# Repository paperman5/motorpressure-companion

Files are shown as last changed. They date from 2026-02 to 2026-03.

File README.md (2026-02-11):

WIP project to create a companion add-on board for [Altus Metrum](https://altusmetrum.org/) flight computers. This companion board is intended to transmit realtime pressure data to the flight computer using a high-pressure pressure sensor for motor characterization similar to the [EasyMotor](https://altusmetrum.org/EasyMotor/), using a low-cost Cortex M0 based microcontroller board ([Adafruit Feather M0 Adalogger](https://www.adafruit.com/product/2796)).

### External Libraries
This project uses the [SercomSPISlave](https://github.com/lenvm/SercomSPISlave) library, since there is no built-in support for using this board in SPI slave mode within Adafruit's libraries. Currently an SPI slave is created using the general-purpose configurable serial port SERCOM4 on the M0.

### Companion Port Pinout
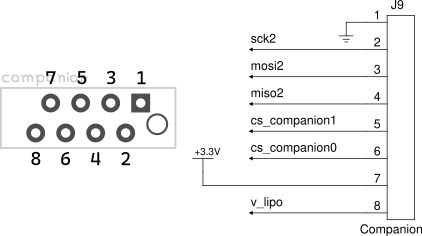
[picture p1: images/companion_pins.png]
Companion Port Pins


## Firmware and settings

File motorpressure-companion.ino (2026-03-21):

// #define REGISTER_DEBUG
// #define ADC_TEST_VALUES // Replaces ADC values with a monotonically increasing value for testing
// #define TRANSMIT_TEST_VALUES // Replaces transmit buffer with testing values
// #define TEST_FLIGHT_TRIGGER
// #define USB_CONNECTED

#include <SPI.h>
#include <FreeStack.h>
#include <SdFat.h>
#include <SdFatConfig.h>
#include <SdFatDebugConfig.h>
#include <sdios.h>
#include <SercomSPISlave.h>
#ifdef REGISTER_DEBUG
  #include <ZeroRegs.h>
#endif

// WIRING (Adafruit Feather M0 Adalogger)
// Flight Computer MOSI <-> Feather PA16 (Labelled D11)
// Flight Computer SCK  <-> Feather PA17 (Labelled D13)
// Flight Computer CS   <-> Feather PA18 (Labelled D10)
// Flight Computer MISO <-> Feather PA19 (Labelled D12)
// Pressure sensor output <-> Feather PB08 (Labelled A1) (3.3V MAX!)

#define CHANNELS 12
#define PACKED_CHANNELS CHANNELS * 4 / 3
#define BOARD_ID 0x7
#define UPDATE_RATE 1 // Companion port update rate, 100Hz ticks
#define ADC_RATE 10 // 1kHz increments, min 1, max 12 (1-12kHz)
#define TRANSMIT_RATE_IDLE 1000   // Radio transmission rate while on the pad/after motor burn (1Hz)
#define TRANSMIT_RATE_FLIGHT 100  // Radio transmission rate while motor is burning (10Hz)
#define FIFO_SIZE 1024
#define SD_MAX_CLOCK 24 // Mhz
#define SD_MIN_CLOCK 8  // Mhz
#define SD_FAT_TYPE 3 // 1 for FAT16/FAT32, 2 for exFAT, 3 for FAT16/FAT32 and exFAT.
#define PIN_SD_CS 4
#define PIN_SD_LED 8
#define ERR_PATTERN_LENGTH 150 // millis between morse code beeps
#define DATA_FILE_PREALLOCATE ADC_RATE * 1000 * 4 * 30  // 4 bytes @ ADC_RATE for 30s
#define SD_WRITE_CHUNK_SIZE 512
#define POST_BURNOUT_DELAY 1 // Additional time to log data after motor has burned out
#define DISCONNECT_RECORD_TIME 15 // Total time to record in case flight computer is disconnected after boost

#if SD_FAT_TYPE == 0
typedef SdFat sd_t;
typedef File file_t;
#elif SD_FAT_TYPE == 1
typedef SdFat32 sd_t;
typedef File32 file_t;
#elif SD_FAT_TYPE == 2
typedef SdExFat sd_t;
typedef ExFile file_t;
#elif SD_FAT_TYPE == 3
typedef SdFs sd_t;
typedef FsFile file_t;
#else  // SD_FAT_TYPE
#error Invalid SD_FAT_TYPE
#endif  // SD_FAT_TYPE

enum Command {
  SETUP = 1,
  FETCH = 2,
  NOTIFY = 3
};
enum FlightState { // From firmware kernel source `ao_flight.h`
  STARTUP = 0,
  IDLE = 1,
  PAD = 2,
  // PAD->BOOST: Baro >20m vert OR accel >2g && vel > 5m/s
  BOOST = 3,
  // BOOST->FAST: accel < -1/4g OR boost time > 15s
  FAST = 4,
  COAST = 5,
  DROGUE = 6,
  MAIN = 7,
  LANDED = 8,
  INVALID = 9,
  TEST = 10
};
enum Error {
  SD_NOT_FOUND = 0,
  SD_FILE_CREATE_ERR = 1,
  SD_FILE_CLOSE_ERR = 2
};
enum ProgramState {
  DISCONNECTED = 0,
  MONITORING = 1,
  RECORDING = 2,
  DONE = 3,
  ERROR = -1
};

// The companion docs are incorrect, the message header is 16 bytes, not 8 bytes.
// There is some extra data after the flight number (from firmware source)
typedef struct {
  volatile uint8_t command;
  volatile uint8_t flight_state;
  volatile uint16_t tick;
  uint16_t         serial;
  uint16_t         flight; // End of companion docs
  volatile int16_t accel;  // From firmware source
	volatile int16_t speed;
	volatile int16_t height;
	uint16_t	       motor_number;
} AltOSMessageHeader;

typedef struct {
  uint16_t board_id;
  uint16_t board_id_inverse;
  uint8_t update_period;
  uint8_t channels;
} AltOSSetupReply;

typedef struct {
  volatile uint16_t data[CHANNELS];
} AltOSFetchReply;

typedef struct {
  uint16_t tick;
  uint16_t value;
} data_t;

Sercom1SPISlave SPISlave;
AltOSMessageHeader message;
AltOSSetupReply setupReply;
AltOSFetchReply fetchReply;
volatile ProgramState state = DISCONNECTED;
ProgramState prevState = DISCONNECTED;
FlightState prevFlightState = INVALID;
sd_t sd;
file_t dataFile;
bool fileCreated = false;
uint8_t rxIndex = 0;
uint8_t txIndex = 0;
uint8_t transmitIndex = 0;
uint16_t dataIndex = 0;
volatile data_t currentData;
// NOTE: `volatile` before pointer type means value at the pointer is volatile,
// `volatile` after pointer type means pointer itself is volatile
volatile data_t dataFifo0[FIFO_SIZE];
volatile data_t dataFifo1[FIFO_SIZE];
// Circular buffer to keep a history of decimated ADC values.
volatile uint16_t transmitBuffer[PACKED_CHANNELS * 2];
// Packed 12bit buffer storing the most recent decimated ADC values for transmission.
// Copied to `fetchReply.data` as soon as a FETCH request is received.
volatile uint8_t tempDataTransmit[CHANNELS * 2];
volatile data_t* volatile currentDataBuffer = dataFifo0;
volatile data_t* volatile dataBufferToWrite = dataFifo1;
volatile bool doDataWrite = false;
volatile bool sdCardIsWriting = false;
volatile bool sdCardOverrun = false;
volatile bool sdCardConnected = false;
volatile bool companionConnected = false;
volatile bool sdInterruptToggleMode = false;
volatile bool companionInterruptToggleMode = false;
volatile bool newMessage = false;
volatile bool isFlightDecimation = false;
volatile uint32_t finalizeDelayTimer = 0;
volatile uint32_t finalizeDelay = 0;
volatile uint32_t adcTicks = 0;
#ifdef ADC_TEST_VALUES
volatile uint16_t adcIndex = 0;
#endif

uint16_t writeCount = 0;
uint32_t loopCount = 0;
uint32_t loopCount2 = 0;


/****** MAIN PROGRAM ******/

void setup() {
  pinMode(PIN_SD_LED, OUTPUT);
  digitalWrite(PIN_SD_LED, LOW);
  Serial.begin(115200);
#ifdef USB_CONNECTED
  while (!Serial);
#endif
  Serial.println(F("Serial started"));

  setupReply.board_id = (uint16_t)BOARD_ID;
  setupReply.board_id_inverse = ~setupReply.board_id;
  setupReply.update_period = (uint8_t)UPDATE_RATE;
  setupReply.channels = (uint8_t)CHANNELS;
  message.command = 0;
  message.flight_state = (uint8_t)INVALID;
  for (int i = 0; i < CHANNELS; i++) {
    fetchReply.data[i] = i;
  }
  memset_volatile(dataFifo0, 0, sizeof(dataFifo0));
  memset_volatile(dataFifo1, 0, sizeof(dataFifo1));
  Serial.print(F("Setup reply initialized: "));
  Serial.printf("%d %d %d %d\n", 
                setupReply.board_id, setupReply.board_id_inverse, 
                setupReply.update_period, setupReply.channels);
  
  init_clocks();
  Serial.println(F("System clocks initialized"));
  SPISlave.SercomInit(SPISlave.MOSI_Pins::PA16, SPISlave.SCK_Pins::PA17, SPISlave.SS_Pins::PA18, SPISlave.MISO_Pins::PA19);
  Serial.println(F("SERCOM1 SPI slave initialized"));
  init_adc();
  Serial.println(F("ADC Initialized"));
  init_adc_timer();
  init_decimation_timer();
  // set_idle_decimation();
  set_flight_decimation();
  Serial.println(F("Timers Initialized"));
  init_eic();
  Serial.println(F("EIC Initialized"));
  // if (!sdCardConnected) {
  //   Serial.println(F("Waiting for SD card to be inserted"));
  //   while(!sdCardConnected) {
  //     delay(100);
  //   }
  // }
  sd_card_init();
  Serial.println(F("SD Card Initialized"));
  // TODO: Setup brownout detector?
  Serial.print(F("Free Stack: "));
  Serial.printf("%d bytes\n", FreeStack());
#ifdef REGISTER_DEBUG
  ZeroRegOptions opts = { Serial, false };
  printZeroRegs(opts);
#endif
  char pattern[3];
  memset(pattern, 1, sizeof(pattern));
  err_blink_pattern(pattern, sizeof(pattern));
}

void loop() {
  // if (newMessage) {
  //   // Serial.println(F("Received Message"));
  //   // print_raw(&message, sizeof(message));
  //   Serial.printf("%d %d %d %d %d %d %d %d %d\n", message.command, message.flight_state, message.tick, 
  //                                                   message.serial, message.flight, message.accel, message.speed, 
  //                                                   message.height, message.motor_number);
  //   newMessage = false;
  // }
  FlightState newFlightState = static_cast<FlightState>(message.flight_state);
  if (prevFlightState != newFlightState) {
    handle_flight_state_change(prevFlightState, newFlightState);
  }
  ProgramState newState = state;
  if (prevState != newState) {
    handle_state_change(prevState, newState);
  }

#ifdef TEST_FLIGHT_TRIGGER
  //TESTING - Trigger flight after 4M loops in MONITORING
  if (newState == MONITORING) {
    loopCount2++;
    if (loopCount2 >= 4000000 && loopCount2 < 4500000) {
      state = RECORDING;
      finalizeDelayTimer = 0;
      finalizeDelay = DISCONNECT_RECORD_TIME;
    }
  }
#endif

  if (newState == RECORDING && doDataWrite) {
    // Serial.println(F("WRITE"));
    doDataWrite = false;
    sdCardIsWriting = true;
    sd_write_buffer_to_file(&dataFile, dataBufferToWrite, sizeof(dataFifo0));
    sdCardIsWriting = false;
    // writeCount++;
    // if (writeCount >= 75) {
    //   state = DONE;
    // }
  }
  else if (newState == RECORDING && finalizeDelayTimer >= (uint32_t)(finalizeDelay * ADC_RATE * 1000) && fileCreated) {
    // Serial.println("1");
    state = DONE;
  }
  if (sdCardOverrun) {
    sdCardOverrun = false;
    Serial.println(F("OVERRUN"));
  }
  if (newState == MONITORING && newFlightState == PAD && fileCreated) {
    digitalWrite(PIN_SD_LED, HIGH);
  }
  prevState = newState;
  prevFlightState = newFlightState;
  loopCount++;
}

void handle_state_change(ProgramState oldState, ProgramState newState) {
  Serial.printf("PROGRAM STATE: %d -> %d\n", oldState, newState);
  if (newState == MONITORING && !fileCreated) {
    Serial.println(F("Creating flight file"));
    if (!create_flight_file((uint8_t)message.flight)) {
      crash_with_error(SD_FILE_CREATE_ERR);
    }
    fileCreated = true;
    Serial.println(F("Flight file created on SD card"));
  }
  else if (newState == RECORDING) {
    set_flight_decimation();
    // set_idle_decimation();
  }
  else if (newState == DONE) {
    if (!finalize_file(&dataFile)) {
      crash_with_error(SD_FILE_CLOSE_ERR);
    }
    Serial.println(F("File Finalized, shutting down SD card"));
    sd.end();
    digitalWrite(PIN_SD_LED, HIGH);
    fileCreated = false;
    set_flight_decimation();
    // set_idle_decimation();
  }
}

void handle_flight_state_change(FlightState oldState, FlightState newState) {
  Serial.printf("FLIGHT STATE: %d -> %d\n", oldState, newState);
  if (newState == STARTUP) {
    if (fileCreated) {
      if (!finalize_file(&dataFile)) {
        crash_with_error(SD_FILE_CLOSE_ERR);
      }
      fileCreated = false;
    }
    state = MONITORING;
    set_flight_decimation();
    // set_idle_decimation();
  }
  else if (newState == BOOST) {
    state = RECORDING;
    finalizeDelayTimer = 0;
    finalizeDelay = DISCONNECT_RECORD_TIME;
    set_flight_decimation();
    // set_idle_decimation();
  }
  else if (oldState == BOOST && newState > BOOST) {
    // Serial.println("2");
    state = RECORDING;
    finalizeDelayTimer = 0;
    finalizeDelay = POST_BURNOUT_DELAY;
    set_flight_decimation();
    // set_idle_decimation();
  }
}

/****** PERIPHERAL REGISTER INITIALIZATION ******/

void init_clocks() {
  // Generic clock 0, is used for companion SPI connection (SERCOM1)
  // GCLK0 is also the main system clock so we don't change it or it will crash
  // GCLK1 is set up as the reference clock for the DFLL48 oscillator, don't change it

  // Load the factory clock calibration data
  uint32_t coarse = (*((uint32_t *) FUSES_DFLL48M_COARSE_CAL_ADDR) & FUSES_DFLL48M_COARSE_CAL_Msk) >> FUSES_DFLL48M_COARSE_CAL_Pos;
  uint32_t fine = (*((uint32_t *) FUSES_DFLL48M_FINE_CAL_ADDR) & FUSES_DFLL48M_FINE_CAL_Msk) >> FUSES_DFLL48M_FINE_CAL_Pos;
  SYSCTRL->DFLLVAL.reg = SYSCTRL_DFLLVAL_COARSE(coarse) | SYSCTRL_DFLLVAL_FINE(fine);

  // Generic clock 2, used for ADC clock
  // Setup with 48Mhz oscillator, divided by 3 for 16Mhz
  GCLK->GENDIV.reg = GCLK_GENDIV_ID(2) | GCLK_GENDIV_DIV(3);
  while (GCLK->STATUS.reg & GCLK_STATUS_SYNCBUSY);
  GCLK->GENCTRL.reg = GCLK_GENCTRL_GENEN | GCLK_GENCTRL_SRC_DFLL48M | GCLK_GENCTRL_ID(2);
  while (GCLK->STATUS.reg & GCLK_STATUS_SYNCBUSY);

  // Generic clock 3, used for Timer clock (TC5)
  // Setup with 48Mhz oscillator, divided by 4 for 12Mhz
  GCLK->GENDIV.reg = GCLK_GENDIV_ID(3) | GCLK_GENDIV_DIV(4);
  while (GCLK->STATUS.reg & GCLK_STATUS_SYNCBUSY);
  GCLK->GENCTRL.reg = GCLK_GENCTRL_GENEN | GCLK_GENCTRL_SRC_DFLL48M | GCLK_GENCTRL_ID(3);
  while (GCLK->STATUS.reg & GCLK_STATUS_SYNCBUSY);

  // Generic clock 4, used for External Interrupt Controller detection
  // Setup with 48Mhz oscillator, divided by 2^23 for 5Hz
  GCLK->GENDIV.reg = GCLK_GENDIV_ID(4) | GCLK_GENDIV_DIV(22);
  while (GCLK->STATUS.reg & GCLK_STATUS_SYNCBUSY);
  GCLK->GENCTRL.reg = GCLK_GENCTRL_GENEN | GCLK_GENCTRL_SRC_DFLL48M | GCLK_GENCTRL_ID(4) | GCLK_GENCTRL_DIVSEL;
  while (GCLK->STATUS.reg & GCLK_STATUS_SYNCBUSY);
}

void init_adc() {
  // // Configure I/O port - PA02 is PINCFG[2], PMUX[1].PMUXE
  // PORT->Group[PORTA].DIRCLR.reg = PORT_PA02;
  // PORT->Group[PORTA].PINCFG[2].bit.INEN = 0x1;
  // PORT->Group[PORTA].PINCFG[2].bit.PMUXEN = 0x1; // Enable pin PA02
  // PORT->Group[PORTA].PMUX[1].bit.PMUXE = 0x1; // Select peripheral function B (ADC input)

  // Configure I/O port - PB08 is GroupB, PINCFG[8], PMUX[4].PMUXE
  PORT->Group[PORTB].DIRCLR.reg |= PORT_PB08;
  PORT->Group[PORTB].PINCFG[8].bit.INEN = 0x1;
  PORT->Group[PORTB].PINCFG[8].bit.PMUXEN = 0x1; // Enable pin PB08
  PORT->Group[PORTB].PMUX[4].bit.PMUXE = 0x1; // Select peripheral function B (ADC input)

  // Reset ADC
  ADC->CTRLA.bit.ENABLE = 0x0;
  while (ADC->STATUS.bit.SYNCBUSY);
  ADC->CTRLA.bit.SWRST = 0x1;
  while (ADC->CTRLA.bit.SWRST || ADC->STATUS.bit.SYNCBUSY);

  // Configure ADC
  GCLK->CLKCTRL.reg = GCLK_CLKCTRL_ID(GCM_ADC) |  // Enable ADC clock
                      GCLK_CLKCTRL_GEN_GCLK2 |    // Use 16MHz GCLK2
                      GCLK_CLKCTRL_CLKEN;
  NVIC_EnableIRQ(ADC_IRQn); // Enable interrupt handler
  NVIC_SetPriority(ADC_IRQn, 1); // 2nd-highest priority
  while (GCLK->STATUS.reg & GCLK_STATUS_SYNCBUSY); // Wait for synchronisation

  // Load the factory calibration data
  // Code from https://blog.thea.codes/reading-analog-values-with-the-samd-adc/
  uint32_t bias = (*((uint32_t *) ADC_FUSES_BIASCAL_ADDR) & ADC_FUSES_BIASCAL_Msk) >> ADC_FUSES_BIASCAL_Pos;
  uint32_t linearity = (*((uint32_t *) ADC_FUSES_LINEARITY_0_ADDR) & ADC_FUSES_LINEARITY_0_Msk) >> ADC_FUSES_LINEARITY_0_Pos;
  linearity |= ((*((uint32_t *) ADC_FUSES_LINEARITY_1_ADDR) & ADC_FUSES_LINEARITY_1_Msk) >> ADC_FUSES_LINEARITY_1_Pos) << 5;
  while (ADC->STATUS.bit.SYNCBUSY);

  ADC->CALIB.reg = ADC_CALIB_BIAS_CAL(bias) | ADC_CALIB_LINEARITY_CAL(linearity);
  ADC->INPUTCTRL.bit.GAIN   = 0xF; // DIV2 gain due to voltage reference being 1/2 VCC
  ADC->INPUTCTRL.bit.MUXNEG = 0x18; // Internal ground as negative input
  // ADC->INPUTCTRL.bit.MUXPOS = 0x00; // PA02 (AIN0) as positive input
  ADC->INPUTCTRL.bit.MUXPOS = 0x02; // PB08 (AIN2) as positive input
  ADC->INTENSET.bit.RESRDY  = 0x1; // Enable result ready interrupt
  ADC->REFCTRL.bit.REFCOMP  = 0x1; // Enable voltage reference compensation
  ADC->REFCTRL.bit.REFSEL   = 0x2; // 1.65V Reference (1/2 VCC)
  ADC->CTRLB.bit.PRESCALER  = 0x2; // Prescaler 16
                                   // NOTE: Max ADC clock is ~2.1MHz, use DIV16 to get 1MHz (48/3/64)
                                   // ALSO NOTE: Max input impedance is ~12MOhm
                                   // https://blog.thea.codes/getting-the-most-out-of-the-samd21-adc/
  ADC->CTRLB.bit.RESSEL     = 0x0; // 12-bit resolution mode
  ADC->CTRLB.bit.CORREN     = 0x0; // Disable digital correction
  ADC->CTRLB.bit.FREERUN    = 0x0; // One-shot conversion mode (Triggered from timer)
  // ADC->CTRLB.bit.FREERUN    = 0x1; // Freerun conversion mode
  ADC->CTRLB.bit.DIFFMODE   = 0x0; // Single-ended conversion
  ADC->AVGCTRL.bit.SAMPLENUM = 0x3; // Average 8 samples
  ADC->AVGCTRL.bit.ADJRES   = 0x3; // Divisor of 8 (for 8 samples)
  // ADC->SAMPCTRL.bit.SAMPLEN = 0x4;

  // Re-enable ADC
  ADC->CTRLA.bit.ENABLE = 0x1;
  while (ADC->STATUS.bit.SYNCBUSY);
}

void init_adc_timer() {
  // Clock source is GCLK3, setup with 12Mhz clock (see init_clocks)
  GCLK->CLKCTRL.reg = GCLK_CLKCTRL_CLKEN | 
                      GCLK_CLKCTRL_GEN_GCLK3 |
                      GCLK_CLKCTRL_ID(GCM_TC4_TC5);
  while (GCLK->STATUS.bit.SYNCBUSY);
  TC5->COUNT16.CTRLA.bit.ENABLE = 0x0;
  while (TC5->COUNT16.STATUS.bit.SYNCBUSY);
  TC5->COUNT16.CTRLA.bit.SWRST = 0x1;
  while (TC5->COUNT16.STATUS.bit.SYNCBUSY);

  NVIC_EnableIRQ(TC5_IRQn);
  NVIC_SetPriority(TC5_IRQn, 0); // Highest priority

  TC5->COUNT16.CTRLA.bit.MODE = 0x0;        // 16-bit counter
  TC5->COUNT16.CTRLA.bit.WAVEGEN = 0x1;     // Match frequency generation (CC0 becomes TOP value)
  TC5->COUNT16.CTRLA.bit.PRESCALER = 0x0;   // DIV1 prescaler for 12MHz clock
  TC5->COUNT16.CTRLA.bit.PRESCSYNC = 0x0;   // Reset counter on next clock, not next prescaled clock
  TC5->COUNT16.CTRLBSET.bit.ONESHOT = 0x0;  // Continue counting on wraparound
  TC5->COUNT16.CTRLBSET.bit.DIR = 0x0;      // Count Up
  TC5->COUNT16.CC[0].reg = (uint16_t) ((12000 / max(1, min(ADC_RATE, 12))) - 1);

  TC5->COUNT16.INTENSET.bit.OVF = 0x1;      // Enable overflow interrupt

  TC5->COUNT16.CTRLA.bit.ENABLE = 0x1;
  while (TC5->COUNT16.STATUS.bit.SYNCBUSY);
}

void init_decimation_timer() {
  // Clock source is GCLK2, setup with 16Mhz clock (see init_clocks)
  GCLK->CLKCTRL.reg = GCLK_CLKCTRL_CLKEN | 
                      GCLK_CLKCTRL_GEN_GCLK2 |
                      GCLK_CLKCTRL_ID(GCM_TCC2_TC3);
  while (GCLK->STATUS.bit.SYNCBUSY);
  TC3->COUNT16.CTRLA.bit.ENABLE = 0x0;
  while (TC3->COUNT16.STATUS.bit.SYNCBUSY);
  TC3->COUNT16.CTRLA.bit.SWRST = 0x1;
  while (TC3->COUNT16.STATUS.bit.SYNCBUSY);

  NVIC_EnableIRQ(TC3_IRQn);
  NVIC_SetPriority(TC3_IRQn, 2); // 2nd-lowest priority

  TC3->COUNT16.CTRLA.bit.MODE = 0x0;        // 16-bit counter
  TC3->COUNT16.CTRLA.bit.WAVEGEN = 0x1;     // Match frequency generation (CC0 becomes TOP value)
  TC3->COUNT16.CTRLA.bit.PRESCSYNC = 0x0;   // Reset counter on next clock, not next prescaled clock
  TC3->COUNT16.CTRLBSET.bit.ONESHOT = 0x0;  // Continue counting on wraparound
  TC3->COUNT16.CTRLBSET.bit.DIR = 0x0;      // Count Up
  TC3->COUNT16.CTRLA.bit.PRESCALER = 0x5;   // DIV64 prescaler for 250kHz clock
  TC3->COUNT16.CC[0].reg = (uint16_t) (250 * TRANSMIT_RATE_IDLE / 16);
  TC3->COUNT16.COUNT.reg = 0x0;

  TC3->COUNT16.INTENSET.bit.OVF = 0x1;      // Enable overflow interrupt

  TC3->COUNT16.CTRLA.bit.ENABLE = 0x1;
  while (TC3->COUNT16.STATUS.bit.SYNCBUSY);
}

void sd_card_init() {
  uint8_t clock = SD_MAX_CLOCK;
  SdSpiConfig* config;
  bool success = false;
  while (!success && clock >= SD_MIN_CLOCK) {
    config = new SdSpiConfig(PIN_SD_CS, DEDICATED_SPI, SD_SCK_MHZ(clock));
    success = sd.begin(*config);
    clock--;
  }
  if (clock < SD_MIN_CLOCK) {
    Serial.println(F("Error initializing SD Card"));
    crash_with_error(SD_NOT_FOUND);
  }
  Serial.print(F("SD card initialized at "));
  Serial.print(++clock);
  Serial.println(F("MHz"));
  NVIC_SetPriority(SERCOM4_IRQn, 3); // Lowest Priority
  // NVIC_SetPriority(SERCOM4_IRQn, 0); // Highest Priority

  sd.ls(LS_SIZE);
}

void init_eic() {
  // Configure the external interrupt controller to detect disconnections from the companion port and the SD card.
  NVIC_DisableIRQ(EIC_IRQn);
  NVIC_ClearPendingIRQ(EIC_IRQn);
  NVIC_SetPriority(EIC_IRQn, 0); // Highest priority
  GCLK->CLKCTRL.reg = GCLK_CLKCTRL_CLKEN |
                      GCLK_CLKCTRL_GEN_GCLK4 |
                      GCLK_CLKCTRL_ID(EIC_GCLK_ID);
  while (GCLK->STATUS.bit.SYNCBUSY);
  EIC->CTRL.bit.ENABLE = 0x0;
  while (EIC->STATUS.bit.SYNCBUSY);
  EIC->CTRL.bit.SWRST = 0x1;
  while (EIC->STATUS.bit.SYNCBUSY);

  // 2 external interrupts, one on the companion port 3.3V line and one on the SD card card detect line.
  // Companion port 3.3V is on A5 (PB02: EXTINT[2])
  // SD Card Detect is on D7 (PA21: EXTINT[5]) (Datasheet pg. 21-23)

  // Configure I/O ports - Input with pulldown
  PORT->Group[PORTB].DIRCLR.reg |= PORT_PB02;
  PORT->Group[PORTB].OUTCLR.reg |= PORT_PB02;
  PORT->Group[PORTB].PINCFG[2].bit.INEN = 0x1;
  PORT->Group[PORTB].PINCFG[2].bit.PULLEN = 0x1;
  PORT->Group[PORTB].PINCFG[2].bit.PMUXEN = 0x1; // Enable pin PB02
  PORT->Group[PORTB].PMUX[1].bit.PMUXE = MUX_PB02A_EIC_EXTINT2; // Select peripheral function A (EIC input)

  // Input with pullup
  PORT->Group[PORTA].DIRCLR.reg |= PORT_PA21;
  PORT->Group[PORTA].OUTSET.reg |= PORT_PA21;
  PORT->Group[PORTA].PINCFG[21].bit.INEN = 0x1;
  PORT->Group[PORTA].PINCFG[21].bit.PULLEN = 0x1;
  PORT->Group[PORTA].PINCFG[21].bit.PMUXEN = 0x1; // Enable pin PA21
  PORT->Group[PORTA].PMUX[10].bit.PMUXO = MUX_PA21A_EIC_EXTINT5; // Select peripheral function A (EIC input)

  // Config is set with index EXTINT[n*8+x] where n is config number and x is filter/sense index (pg. 353)
  // These are initially configured for high-level detect to get a confirmed state before switching
  //  to both-edge-detect mode, where each interrupt will toggle the connected state
  EIC->CONFIG[0].bit.SENSE2 = 0x4; // High-level detect
  EIC->CONFIG[0].bit.FILTEN2 = 0x1; // Filter enabled
  EIC->CONFIG[0].bit.SENSE5 = 0x4; // High-level detect
  EIC->CONFIG[0].bit.FILTEN5 = 0x1; // Filter enabled

  EIC->INTENSET.bit.EXTINT2 = 0x1;
  EIC->INTENSET.bit.EXTINT5 = 0x1;

  EIC->CTRL.bit.ENABLE = 0x1;
  while (EIC->STATUS.bit.SYNCBUSY);

  NVIC_EnableIRQ(EIC_IRQn);
}

/****** INTERRUPT HANDLERS ******/

// ADC trigger timer
void TC5_Handler() {
  TC5->COUNT16.INTFLAG.bit.OVF = 0x1; // Clear the overflow flag
  ADC->SWTRIG.bit.START = 0x1; // Start an ADC conversion
  finalizeDelayTimer++;
  adcTicks++;
}

// Decimation timer
void TC3_Handler() {
  TC3->COUNT16.INTFLAG.bit.OVF = 0x1; // Clear the overflow flag
  transmitBuffer[transmitIndex++] = currentData.value;
  transmitIndex = transmitIndex % (sizeof(transmitBuffer) / sizeof(transmitBuffer[0]));
  fill_temp_transmit_buffer();
}
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

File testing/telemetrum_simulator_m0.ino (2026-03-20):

#include <SPI.h>


#define PIN_BUTTON 5
#define PIN_CS 0
#define PIN_EN 1

enum Command {
  NONE = 0,
  SETUP = 1,
  FETCH = 2,
  NOTIFY = 3
};
enum FlightState { // From firmware kernel source `ao_flight.h`
  STARTUP = 0,
  IDLE = 1,
  PAD = 2,
  // PAD->BOOST: Baro >20m vert OR accel >2g && vel > 5m/s
  BOOST = 3,
  // BOOST->FAST: accel < -1/4g OR boost time > 15s
  FAST = 4,
  COAST = 5,
  DROGUE = 6,
  MAIN = 7,
  LANDED = 8,
  INVALID = 9,
  TEST = 10
};

typedef struct {
  volatile uint8_t command;
  volatile uint8_t flight_state;
  volatile uint16_t tick;
  uint16_t         serial;
  uint16_t         flight; // End of companion docs
  volatile int16_t accel;  // From firmware source
	volatile int16_t speed;
	volatile int16_t height;
	uint16_t	       motor_number;
} AltOSMessageHeader;

typedef struct {
  uint16_t board_id;
  uint16_t board_id_inverse;
  uint8_t update_period;
  uint8_t channels;
} AltOSSetupReply;

SPISettings spisettings(200000, MSBFIRST, SPI_MODE0);
volatile uint16_t startTick = 0;
AltOSMessageHeader message;
FlightState prevFlightState = INVALID;
volatile bool connected = false;
volatile bool sendFetch = false;
volatile bool sentThisTick = false;
volatile uint8_t setupsSent = 0;
volatile uint8_t channels = 0;
uint16_t stageTickCounts[11];
uint8_t rxBuffer[40];
uint8_t txBuffer[40];

void setup() {
  Serial.begin(115200);
  while (!Serial);
  init_message_startup();
  setupStages();
  init_clocks();
  init_tick_timer();
  SPI.begin();
  pinMode(PIN_BUTTON, INPUT_PULLUP);
  pinMode(PIN_LED, OUTPUT);
  pinMode(PIN_CS, OUTPUT);
  pinMode(PIN_EN, OUTPUT);
  digitalWrite(PIN_EN, HIGH);
  memset(rxBuffer, 0, sizeof(rxBuffer));
  memset(txBuffer, 0, sizeof(txBuffer));
  Serial.println(F("Initialized"));
}

void loop() {
  FlightState nextFlightState = static_cast<FlightState>(message.flight_state);
  bool buttonPressed = !digitalRead(PIN_BUTTON);
  digitalWrite(PIN_LED, buttonPressed);
  uint16_t tdiff = message.tick - startTick;

  if (nextFlightState != prevFlightState) {
    Serial.printf("STATE: %d -> %d (%d)\n", prevFlightState, nextFlightState, message.tick);
    if (nextFlightState < INVALID && prevFlightState < INVALID && nextFlightState > STARTUP && prevFlightState > STARTUP && connected) {
      send_notify();
    }
  }

  if ((nextFlightState == INVALID || nextFlightState == STARTUP) && tdiff < stageTickCounts[STARTUP] && message.tick % 10 == 0 && !sentThisTick) {
    if (message.tick > 400) {
      message.flight_state = STARTUP;
    }
    sentThisTick = true;
    send_startup();
  }

  if ((nextFlightState == INVALID || nextFlightState == STARTUP) && tdiff >= stageTickCounts[STARTUP]) {
    message.flight_state = PAD;
    startTick = message.tick;
    init_message_setup();
  }

  if (nextFlightState == PAD && message.tick % 100 == 0 && !sentThisTick && !connected) {
    sentThisTick = true;
    send_setup();
  }

  if (nextFlightState == PAD && buttonPressed && connected) {
    message.flight_state = BOOST;
    startTick = message.tick;
  }

  if (nextFlightState >= BOOST && nextFlightState < LANDED && tdiff >= stageTickCounts[nextFlightState] && connected) {
    message.flight_state++;
    startTick = message.tick;
  }

  if (sendFetch && connected) {
    sendFetch = false;
    send_fetch();
  }
  
  prevFlightState = nextFlightState;
}

void setupStages() {
  memset(stageTickCounts, 0, sizeof(stageTickCounts));
  // Values are from some old flight data
  stageTickCounts[STARTUP] = 596;
  stageTickCounts[BOOST] = 275;
  stageTickCounts[FAST] = 657;
  stageTickCounts[COAST] = 2117;
  stageTickCounts[DROGUE] = 2688;
  stageTickCounts[MAIN] = 907;
}

void init_message_startup() {
  memset(&message, 0, sizeof(message));
  message.flight_state = INVALID;
}

void init_message_setup() {
  message.command = SETUP;
  message.serial = 0x3713;
  message.flight = 0xADDE;
  message.accel = 0xEFBE;
  message.speed = 0xADDE;
  message.height = 0xEFBE;
  message.motor_number = 0x3713;
}

void init_clocks() {
  // Generic clock 0, is used for companion SPI connection (SERCOM1)
  // GCLK0 is also the main system clock so we don't change it or it will crash
  // GCLK1 is set up as the reference clock for the DFLL48 oscillator, don't change it

  // Load the factory clock calibration data
  uint32_t coarse = (*((uint32_t *) FUSES_DFLL48M_COARSE_CAL_ADDR) & FUSES_DFLL48M_COARSE_CAL_Msk) >> FUSES_DFLL48M_COARSE_CAL_Pos;
  uint32_t fine = (*((uint32_t *) FUSES_DFLL48M_FINE_CAL_ADDR) & FUSES_DFLL48M_FINE_CAL_Msk) >> FUSES_DFLL48M_FINE_CAL_Pos;
  SYSCTRL->DFLLVAL.reg = SYSCTRL_DFLLVAL_COARSE(coarse) | SYSCTRL_DFLLVAL_FINE(fine);

  // Generic clock 2, used for ticker clock
  // Setup with 48Mhz oscillator, divided by 12 for 4Mhz
  GCLK->GENDIV.reg = GCLK_GENDIV_ID(2) | GCLK_GENDIV_DIV(12);
  while (GCLK->STATUS.reg & GCLK_STATUS_SYNCBUSY);
  GCLK->GENCTRL.reg = GCLK_GENCTRL_GENEN | GCLK_GENCTRL_SRC_DFLL48M | GCLK_GENCTRL_ID(2);
  while (GCLK->STATUS.reg & GCLK_STATUS_SYNCBUSY);
}

void init_tick_timer() {
  // Clock source is GCLK2, setup with 4Mhz clock (see init_clocks)
  GCLK->CLKCTRL.reg = GCLK_CLKCTRL_CLKEN | 
                      GCLK_CLKCTRL_GEN_GCLK2 |
                      GCLK_CLKCTRL_ID(GCM_TC4_TC5);
  while (GCLK->STATUS.bit.SYNCBUSY);
  TC5->COUNT16.CTRLA.bit.ENABLE = 0x0;
  while (TC5->COUNT16.STATUS.bit.SYNCBUSY);
  TC5->COUNT16.CTRLA.bit.SWRST = 0x1;
  while (TC5->COUNT16.STATUS.bit.SYNCBUSY);

  NVIC_EnableIRQ(TC5_IRQn);
  NVIC_SetPriority(TC5_IRQn, 0); // Highest priority

  TC5->COUNT16.CTRLA.bit.MODE = 0x0;        // 16-bit counter
  TC5->COUNT16.CTRLA.bit.WAVEGEN = 0x1;     // Match frequency generation (CC0 becomes TOP value)
  TC5->COUNT16.CTRLA.bit.PRESCALER = 0x5;   // DIV64 prescaler for 62.5kHz clock
  TC5->COUNT16.CTRLA.bit.PRESCSYNC = 0x0;   // Reset counter on next clock, not next prescaled clock
  TC5->COUNT16.CTRLBSET.bit.ONESHOT = 0x0;  // Continue counting on wraparound
  TC5->COUNT16.CTRLBSET.bit.DIR = 0x0;      // Count Up
  TC5->COUNT16.CC[0].reg = 625; // 10ms

  TC5->COUNT16.INTENSET.bit.OVF = 0x1;      // Enable overflow interrupt

  TC5->COUNT16.CTRLA.bit.ENABLE = 0x1;
  while (TC5->COUNT16.STATUS.bit.SYNCBUSY);
}

void TC5_Handler() {
  TC5->COUNT16.INTFLAG.bit.OVF = 0x1; // Clear the overflow flag
  message.tick += 1;
  sentThisTick = false;
  if (message.flight_state >= PAD && message.flight_state < INVALID && connected) {
    sendFetch = true;
  }
}

void send_startup() {
  if (message.tick % 10 == 0){
    Serial.print(F("STARTUP"));
    Serial.println(message.tick);
    send_message(sizeof(message));
  }
}
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

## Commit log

2026-02-11 Basic functional companion board!
2026-02-12 Basic ADC setup
2026-02-13 Trigger ADC with and RTC interrupt
2026-02-16 Make ADC run at 50k intervals
2026-02-24 Working SD card at 10kHz ADC
2026-03-18 Add fritzing file
    [companion.fzz]
2026-03-18 Software for assembled hardware prototype
2026-03-19 External interrupts for companion & SD card
2026-03-19 Fix Flight & ADC timing issues
    [motorpressure-companion.ino]
2026-03-19 Fix flight decimation rate & always use flight decimation rate
    [motorpressure-companion.ino]
2026-03-20 Turn on LED when properly prepped
